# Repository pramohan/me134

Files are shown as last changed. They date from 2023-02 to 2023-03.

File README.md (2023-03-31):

# 5-DoF Robot Arm for the Operation Board Game

Teammates' Github: kgauld1, harnett1, sravaniboggaram 

## Game Design
The project is based off of the game Operation. In this game, there is a board with cutouts of various shapes, each with matching game pieces that fit into the corresponding cutouts. In the classic version of the game, the goal is to remove all of the pieces from their cutouts without the player or the pieces touching the cutout edges.

Our game is a variation on Operation in which the player controls a robotic arm to remove or insert the pieces from the game board. In leveraging a robotic arm, we are also able to autonomously insert and remove pieces from the board. As such, the goal is to make a fully functional game in which the robot can autonomously control the board state, as well as respond to manual commands from a user operating a control box.

## Hardware Design
To learn more about the robot's hardware, go to [the hardware page](hardware.md).

## Software Design
To learn more about the robot's software, go to [the software page](software.md).

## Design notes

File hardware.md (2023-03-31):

[Go back](https://github.com/pramohan/me134)

## Hardware Design
We opted to construct an arm with 5 degrees of freedom and an electromagnetic end effector. There is a pan DOF at both the base and end effector, with 3 tilt DOFs chained together between them. As it has the highest torque requirement, we chose an X8-16 Nm motor for the base tilt joint. All other motors were X5-9 or X5-4 motors, as they required lower torque ranges. For the end effector, we chose a 5V electromagnet with a 2.5kg mass rating. The electromagnet was directly mounted to the bottom of the last panning motor to give us direct rotational freedom in its positioning. The use of an electromagnet limited us to making the game pieces out of thin 30 gauge steel sheet metal, which can be easily picked up and dropped by the electromagnet. The image below displays the constructed robot arm.


We designed the game board by laser cutting a 2ft x 2ft acrylic sheet. The board, pieces, and holes were distinct colors from both each other and the table. This enabled us to identify and classify gameboard components by color. The board is shown below.


For detecting contact between the game board and the piece during gameplay we chose to implement capacitive touch sensing which required copper tape, an ESP32 Wroom, and roughly 0.75m of 30 AWG wire. The ESP32 was chosen since we already had a board and it natively has capacitive touch pins to make measurements easy to read with one command. While this has not been integrated in the current system–given our priorities in getting more complex systems such as camera detection working–its isolated tests were successful.

For the manual control, there are two modes of operation. The first mode leverages 5 potentiometers in directly controlling the angles of each of the arm joints. The second mode uses a joystick to control the cartesian velocity of the tip of the robot. There is a toggle switch to switch between the two modes, as well as a toggle switch to change the z direction of the joystick (which is controlled by pressing down on the joystick). There are also 3 LEDs to indicate the status of the internal microcontroller as well as which mode is active at the time of operation. The control box is enclosed within a laser-cut acrylic box measuring 10x15x30 cm.


The final hardware diagram is displayed below:


[Go back](https://github.com/pramohan/me134)

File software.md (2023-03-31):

[Go back](https://github.com/pramohan/me134)
# Software Setup

## Detectors
A Logitech web camera mounted above the table gave an aerial view of the game board.
 
The camera has multiple uses, one for reporting points of interest in the table frame, and another for detecting color contour boundaries. When the program is run, the 
camera waits and watches for 4 specific ARUCO tags before continuing. It then correlates the pixel position of the tags with their known table frame coordinates in order 
to compute a matrix that can compute the transform from camera coordinates to table coordinates. This process is run each time at startup, so it is robust to changes in 
table or camera location - as long as the ARUCOs are located at the same table coordinates, the position of the tags in the camera does not matter. Measuring the 
location of the tags with sub-centimeter accuracy in the table frame allowed the camera to return table frame coordinates of points of interest with sub-centimeter 
accuracy as well. We programmed our executable to wait until this camera setup is complete, so the robot will not move until all four ARUCOs are visible. An image of ARUCO detection is displayed below.



The other use of the camera is as a color contour detector. The pieces for our game were dark pink, and the board was placed on top of green felt, so that the holes could be detected by looking for green color. Finally, the board itself was blue. We tuned the HSV intervals of the detector until it could detect the boundaries of the pieces and holes with very little noise. This contour also allowed us to obtain its centroid, and thus the center of the piece. 

We attempted to obtain orientation of the pieces by using PCA; however, this only successfully worked for the bone-shaped piece. This method returned noisy and jittery angles for the other pieces. To get around this issue, we developed another method of obtaining orientation, which involved getting the line segment from the centroid to the point on the contour farthest from the centroid, and finding the angle of the segment. We were able to differentiate the bone from the other pieces using the ratio of the sides of the minimum area bounding rectangle, which was further from 1 because of its elongated shape. Thus, we could use PCA on the bone-shaped piece, and our custom orientation method on the other pieces. 



Additionally, we could use the cv2.matchShapes function to measure similarity between piece and hole contours. This allowed us to match pieces to their respective holes during autonomous board setup. In the picture below, we can see dissimilarity coefficients between the red star and each of the holes. This means that the smaller the number is, the better match it is to the star. As expected, the star shaped hole contains the smallest dissimilarity coefficient. 



The blue color of the board was only used during the automated removal of pieces from the game board.  We fit a rectangle to the blue contour, and only remove pieces if their centroid falls within the bounds of the rectangle. 

## Micro-ROS
Our controller was implemented using micro-ROS. The micro-ROS framework allows us to create a node on an Arduino Nano RP2040 Connect which transmits state information over serial communication. To establish this connection, we built a micro-ROS agent on the NUC, which read in serial data from the node on the RP2040. This worked fine, but after some time began causing a data stream conflict with the Ethernet connection to the Hebi motors. Due to this conflict, we were forced to find an alternative way to connect the controller to the main ROS node on the NUC. To this effect, we flashed a Raspberry Pi 4 with Ubuntu Jammy 22.04 running ROS 2 Humble and created a WiFi link to the NUC over the robotnet network. By establishing an SSH connection between the NUC and Raspberry Pi, we were able to wirelessly transmit publishers and subscribers between the two computers.

All development on the Micro-ROS node was done in C++, using the rclcpp library to communicate with ROS and the Arduino library to read GPIO data. Code was flashed to the microcontroller using PlatformIO in VSCode, which allowed for flashing the microcontroller with the micro-ROS firmware.
We ran into two major issues with the RP2040 Connect. The first of these issues was due to the lack of available analog pins. The RP2040 Connect has 8 analog pins onboard, but only 4 of these pins are accessible for use, as the micro-ROS firmware locks the last 4 analog pins for wireless transport modes, which we did not use. Since we needed to use 5 potentiometers for joint control and 2 for the joystick, we needed to expand the number of analog ports available on the RP2040. As such, we added an MCP3008 IC to the system, which adds 8 analog inputs through an Analog-Digital Converter (ADC) communicating to the RP4040 through the Serial Peripheral Interface (SPI). 

Our second major issue was due to the limitations of micro-ROS. The micro-ROS firmware defines the controller as “very low mem”, allowing for no more than 2 publishers and 1 subscriber. Ideally, we would have had multiple binary publishers for each button, so this forced us to create 2 Int64 subscribers which contained all of the data for the various components in its digits. The first of these subscribers was for the potentiometer values, with 15 digits, with each potentiometer value ranging from 0 to 999. The second publisher published the joystick as the first 7 digits with 3 for each direction and 1 for the up/down button, followed by 3 digits for the button/toggle switch states and one digit for the state of the capacitive touch sensor.

## Manual Control
Our primary means of motion integration was done through the implementation of splines taking the robot through either task or joint space. We begin by integrating the manual control. For manual control, we subscribe to the topics from the micro-ROS node over the network. For each of these control modes, there is a unique starting position. For the joint control, we want to set the joints to match the initial potentiometer position, while for joystick control we want to set the joints to a safe position specific to the joystick operation. After setting these segments, we update the position directly with filtered input values. 

For potentiometer control, we implement a first-order filter on the potentiometer rotation values. This creates a smoothed update sequence, so we are able to directly write the filtered potentiometer positions to the HEBIs after the startup splines are complete.

For joystick control, we have constant velocity control in the direction of the joystick. As the velocity is sufficiently slow, we are able to numerically integrate, adding a set distance at every time step of the runtime. The nominal velocity control adds 1 mm per time step, giving a velocity of 10cm/s. By maxing out the control range in either direction, the velocity can increase up to a maximum velocity of 20 cm/s in either direction. As this motion is fairly slow, the robot is able to move smoothly while controlled. To implement the actual control, we have a saved desired joystick position variable which updates with the velocity command. At each time step, the ikin of this desired position is computed, and the resultant joint states are sent to the motor controller.

Now, we must switch between the two manual control modes based on the state of the select toggle switch on the controller box. At the beginning of the update loop for each mode, there is a check for a mode mismatch. If the software operation mode does not match the controller toggle switch, the mode is switched by executing the initial spline case for the selected mode.

## Autonomous Control
We also had 2 separate modes of autonomous control. For these modes, we subscribe to the detector topics to find the position of contours and their matches. Both of these methods start with the same spline, sending the robot off of the board to make sure the entire board can be seen by the camera. 

First, we consider autonomous removal from the board. For this, we only care about the subscriber giving the list of pieces currently on the board. We send the robot to the safe position at the start, then check the board. If there are any pieces on the board, it picks one and updates the list of splines to take it off the board. The removal motion goes to a point directly above the dropoff location, then moves straight down to drop the piece. This ensures the robot does not move into the board while moving to the dropoff location.
 
Autonomous insertion has a similar movement path to the autonomous removal, but instead of 3D splines in xyz cartesian space, we must compute splines in 5D xyz tilt pan space, as we are controlling the final pan angle of the tip to ensure the piece has the right orientation when being dropped in. 

For overlapping chunks, we have a list of positions which do not match holes on the board. If there are no more pieces which match holes on the board, we go to this list and move the first centroid to one of 4 safe positions. After moving this centroid, it rechecks the board and continues. This allows for overlapping pieces to be moved then matched to hole shape to place onto the board.

Combining manual and autonomous motion, we have a flag in the code which determines the mode and any transitions. Currently, the flag is set such that the robot completes one of the two autonomous motions then switches to user input, but the modes are built with modularity in mind, so these transitions can be easily switched.

The complete diagram of the software is shown below:


[Go back](https://github.com/pramohan/me134)

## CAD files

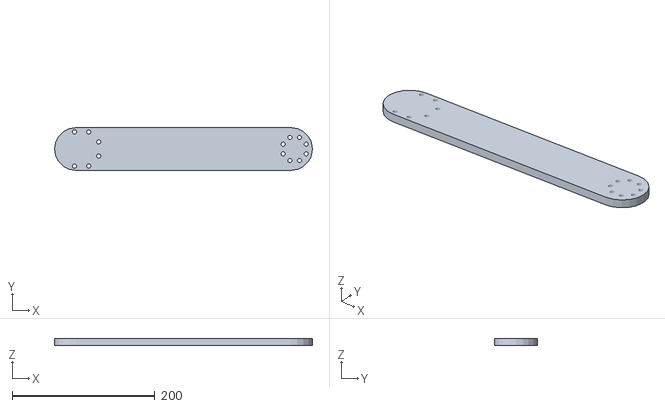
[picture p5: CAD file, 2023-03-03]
install/basic134/share/basic134/meshes/link.STL
362.0 x 60.0 x 10.0

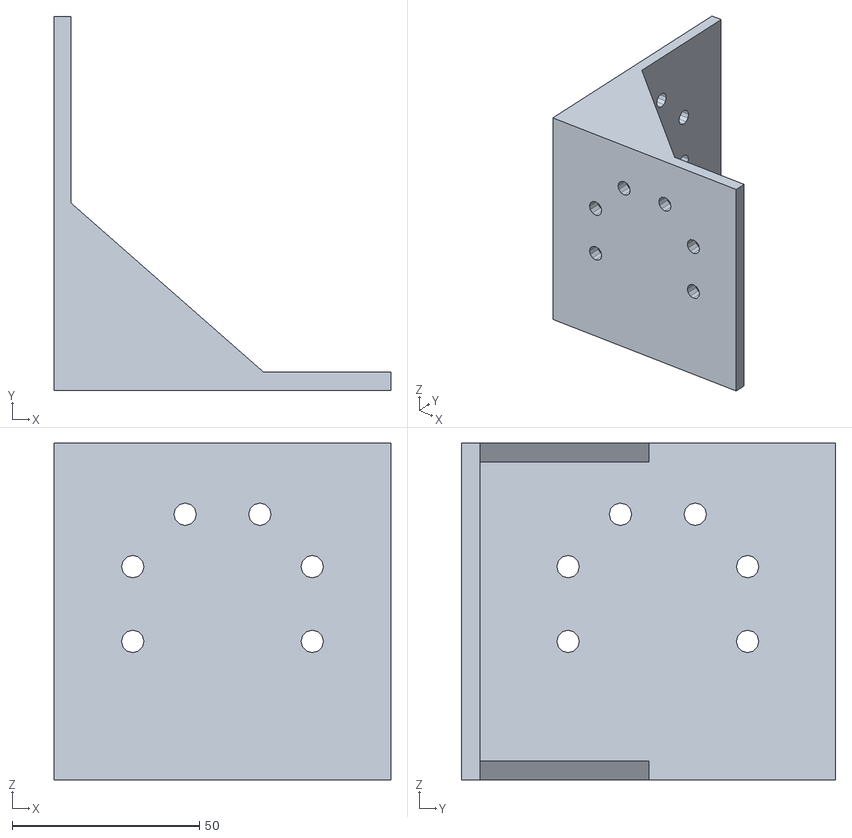
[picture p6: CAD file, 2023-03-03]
install/operation/share/operation/meshes/lbracket2.STL
90.0 x 100.0 x 90.0

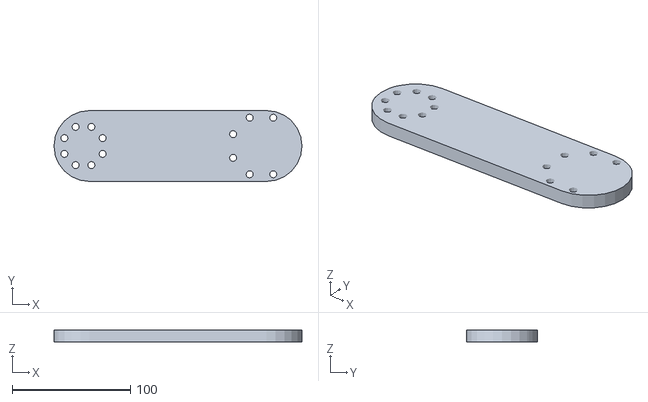
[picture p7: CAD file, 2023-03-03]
install/basic134/share/basic134/meshes/link_short.STL
210.0 x 60.0 x 10.0

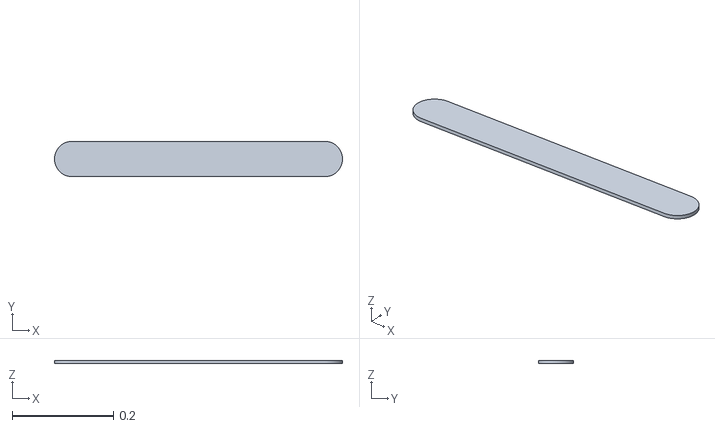
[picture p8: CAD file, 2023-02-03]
install/basic134/share/basic134/meshes/basiclink.stl
0.57 x 0.07 x 0.00635

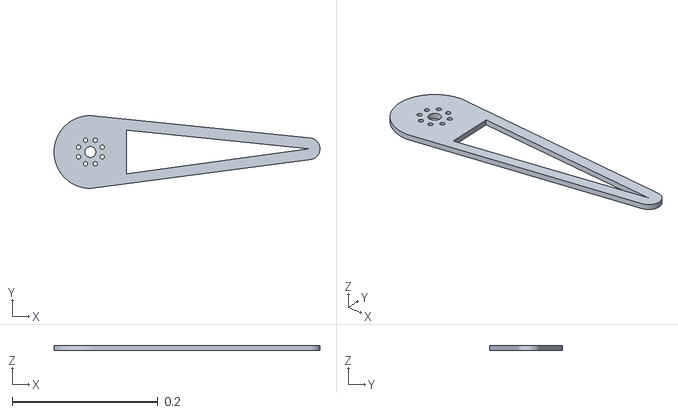
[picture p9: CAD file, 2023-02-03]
install/basic134/share/basic134/meshes/lowerarm.stl
0.365 x 0.1 x 0.00635

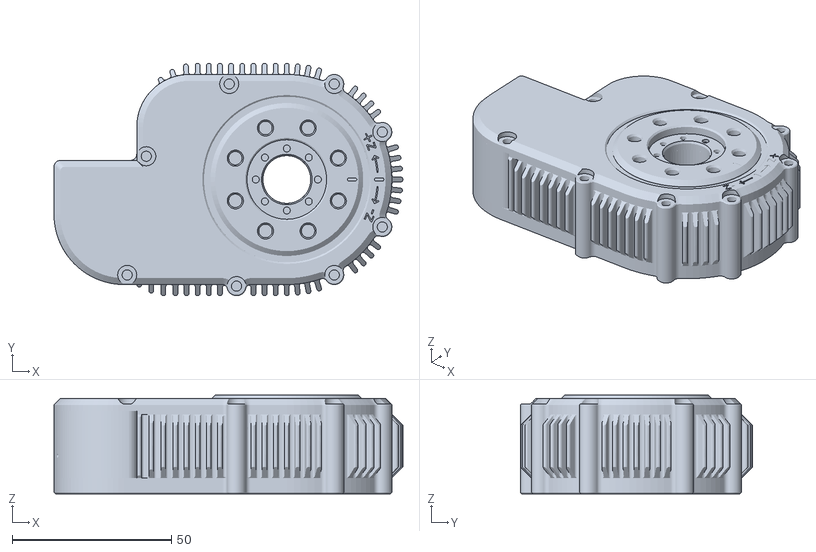
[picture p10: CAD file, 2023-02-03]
install/operation/share/operation/meshes/X5.stl
109.6 x 73.0 x 31.1

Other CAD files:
build/basic134/meshes/link.STL
build/operation/meshes/link_short.STL
build/basic134/meshes/link_short.STL
build/operation/meshes/link.STL
build/basic134/meshes/basiclink.stl
build/operation/meshes/arm_base.stl
build/basic134/meshes/arm_base.stl
build/operation/meshes/lbracket.STL
build/basic134/meshes/lowerarm.stl
build/operation/meshes/basiclink.stl
build/basic134/meshes/X5.stl
build/basic134/meshes/X8.stl
build/basic134/meshes/lbracket.STL
build/operation/meshes/X5.stl
build/operation/meshes/X8.stl
build/operation/meshes/lbracket2.STL
build/operation/meshes/lowerarm.stl
install/basic134/share/basic134/meshes/X8.stl
install/basic134/share/basic134/meshes/arm_base.stl
install/basic134/share/basic134/meshes/lbracket.STL
install/operation/share/operation/meshes/X8.stl
install/operation/share/operation/meshes/arm_base.stl
install/operation/share/operation/meshes/lbracket.STL

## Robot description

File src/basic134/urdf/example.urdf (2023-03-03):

<?xml version="1.0"?>

<robot name="example">
  
  <!-- *************************************************** -->
  <!-- ***************** Kinematic Chain ***************** -->
  <!-- *************************************************** -->
  <!-- Note the 'origin' tag in the joints defines the
       shift and reorientation before the continuous joint
       rotates around the 'axis'. -->


  <!-- Locate the base plate at the world origin. -->
  <joint name="place" type="fixed">
    <parent link="world"/>
    <child link="baseplate"/>
    <origin xyz="0 0 0" rpy="0 0 0"/>
  </joint>

  <!-- Shift across the base plate to the base motor. -->
  <joint name="baseplate" type="fixed">
    <parent link="baseplate"/>
    <child link="basemotor"/>
    <origin xyz="0.08 0 0.012" rpy="0 0 0"/>
  </joint>

  <!-- Base motor.  Thickness: X5 = 31.1mm, X8 = 45.1mm -->
  <joint name="base" type="continuous">
    <parent link="basemotor"/>
    <child link="lbracket"/>
    <origin xyz="0 0 0.0311" rpy="0 0 0"/>
    <axis xyz="0 0 1"/>
  </joint>

  <!-- Shift across the L bracket -->
  <joint name="lbracket" type="fixed">
    <parent link="lbracket"/>
    <child link="shouldermotor"/>
    <origin xyz="0 -0.035 0.075" rpy="1.5708 0 3.1415"/>
  </joint>

  <!-- Shoulder motor.  Thickness: X5 = 31.1mm, X8 = 45.1mm -->
  <joint name="shoulder" type="continuous">
    <parent link="shouldermotor"/>
    <child link="upperarm"/>
    <origin xyz="0 0 0.0451" rpy="0 0 0"/>
    <axis xyz="0 0 1"/>
  </joint>

  <!-- Shift across the upper arm (1/4in thickness) -->
  <joint name="upperarm" type="fixed">
    <parent link="upperarm"/>
    <child link="elbowmotor"/>
    <origin xyz="0 0.3 0" rpy="0 3.1415 -1.5708"/>
  </joint>

  <!-- Elbow motor.  Thickness: X5 = 31.1mm, X8 = 45.1mm -->
  <joint name="elbow" type="continuous">
    <parent link="elbowmotor"/>
    <child link="lowerarm"/>
    <origin xyz="0 0 .0311" rpy="0 0 0"/>
    <axis xyz="0 0 1"/>
  </joint>

  <!-- Shift across the upper arm (1/4in thickness) -->
  <joint name="lowerarm" type="fixed">
    <parent link="lowerarm"/>
    <child link="wristmotor"/>
    <origin xyz="0 0.30095 0" rpy="0 3.1415 1.5708"/>
  </joint>

  <!-- Wrist motor.  Thickness: X5 = 31.1mm, X8 = 45.1mm -->
  <joint name="wrist" type="continuous">
    <parent link="wristmotor"/>
    <child link="hand"/>
    <origin xyz="0 0 .0311" rpy="0 0 0"/>
    <axis xyz="0 0 1"/>
  </joint>

  <!-- Shift across the hand (1/4in thickness) -->
  <joint name="hand" type="fixed">
    <parent link="hand"/>
    <child link="lbracket2"/>
    <origin xyz="0 0.15266 0" rpy="0 0 0"/>
  </joint>

  <!-- Shift across the second L bracket -->
  <joint name="lbracket2" type="fixed">
    <parent link="lbracket2"/>
    <child link="fingermotor"/>
    <origin xyz=".045 0 -0.0525" rpy="-1.5708 0 -1.5708"/>
  </joint>

  <!-- Finger motor.  Thickness: X5 = 31.1mm, X8 = 45.1mm -->
  <joint name="finger" type="continuous">
    <parent link="fingermotor"/>
    <child link="tip"/>
    <origin xyz="0 0 .0311" rpy="0 0 0"/>
    <axis xyz="0 0 1"/>
  </joint>
  
  <!-- *************************************************** -->
  <!-- *************** Visual Link Elements ************** -->
  <!-- *************************************************** -->
  <!-- Note collada .dae files have better color/texture   -->
  <!-- suppport that STL files.                            -->

  <!-- Colors -->
  <material name="wood">  <color rgba="0.82 0.62 0.04 1"/>  </material>
  <material name="hebi">  <color rgba="0.82 0.06 0.06 1"/>  </material>

  <!-- World can't take a visual element (at least in Gazebo). -->
  <link name="world"/>

  <link name="baseplate">
    <visual>
      <origin xyz = "0.07 0 0" rpy = "0 0 0"/>
      <geometry>
        <cylinder length="0.012" radius="0.08"/>
      </geometry>
      <material name="wood"/>
    </visual>
  </link>

  <link name="basemotor">
    <visual>
      <geometry>
        <mesh filename="package://basic134/meshes/X5.stl" scale="0.001 0.001 0.001"/>
      </geometry>
      <material name="hebi"/>
    </visual>
  </link>

  <link name="lbracket">
    <visual>
      <origin xyz = "0.038 0.03 0" rpy = "0 0 3.1415"/>
      <geometry>
        <mesh filename="package://basic134/meshes/lbracket.STL" scale="0.001 0.001 0.001"/>
      </geometry>
      <material name="wood"/>
    </visual>
  </link>

  <link name="shouldermotor">
    <visual>
      <geometry>
        <mesh filename="package://basic134/meshes/X8.stl" scale="0.001 0.001 0.001"/>
      </geometry>
      <material name="hebi"/>
    </visual>
  </link>

  <link name="upperarm">
    <visual>
      <origin xyz = "0 0.15 0.0065" rpy = "0 1.5708 1.5708"/>
      <geometry>
        <mesh filename="package://basic134/meshes/arm_base.stl" scale="0.001 0.001 0.001"/>
      </geometry>
      <material name="wood"/>
    </visual>
  </link>

  <link name="elbowmotor">
    <visual>
      <geometry>
        <mesh filename="package://basic134/meshes/X5.stl" scale="0.001 0.001 0.001"/>
      </geometry>
      <material name="hebi"/>
    </visual>
  </link>

  <link name="lowerarm">
    <visual>
      <origin xyz = "0.03 0.337 0.01" rpy = "3.1415 0 -1.5708"/>
      <geometry>
        <mesh filename="package://basic134/meshes/link.STL" scale="0.001 0.001 0.001"/>
      </geometry>
      <material name="wood"/>
    </visual>
  </link>

  <link name="wristmotor">
    <visual>
      <geometry>
        <mesh filename="package://basic134/meshes/X5.stl" scale="0.001 0.001 0.001"/>
      </geometry>
      <material name="hebi"/>
    </visual>
  </link>

  <link name="hand">
    <visual>
      <origin xyz = "0.03 -0.0247 0" rpy = "0 0 1.5708"/>
      <geometry>
        <mesh filename="package://basic134/meshes/link_short.STL" scale="0.001 0.001 0.001"/>
      </geometry>
      <material name="wood"/>
    </visual>
  </link>

  <link name="lbracket2">
    <visual>
      <origin xyz = "0.045 0.0503 0" rpy = "-1.5708 0 3.1415"/>
      <geometry>
        <mesh filename="package://operation/meshes/lbracket2.STL" scale="0.001 0.001 0.001"/>
      </geometry>
      <material name="wood"/>
    </visual>
  </link>

  <link name="fingermotor">
    <visual>
      <geometry>
        <mesh filename="package://basic134/meshes/X5.stl" scale="0.001 0.001 0.001"/>
      </geometry>
      <material name="hebi"/>
    </visual>
  </link>
  
  <link name="tip"/>

</robot>

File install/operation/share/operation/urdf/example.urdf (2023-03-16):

<?xml version="1.0"?>

<robot name="KillerRover2000">
  
  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
  <joint name="place" type="fixed">
    <parent link="world"/>
    <child link="baseplate"/>
    <origin xyz="0 0 0" rpy="0 0 0"/>
  </joint>

  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
  <joint name="baseplate" type="fixed">
    <parent link="baseplate"/>
    <child link="motor0"/>
    <origin xyz="0 0 0" rpy="0 0 0"/>
  </joint>

  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
  <joint name="theta0" type="continuous">
    <parent link="motor0"/>
    <child link="basecylinder"/>
    <origin xyz="0 0 0" rpy="0 0 0"/>
    <axis xyz="0 0 1"/>
  </joint>

  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
  <joint name="basecylinder" type="fixed">
    <parent link="basecylinder"/>
    <child link="motor1link"/>
    <origin xyz="0 0 0.0127" rpy="0 0 0"/>
  </joint>

  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
  <joint name="motor1link" type="fixed">
    <parent link="motor1link"/>
    <child link="motor1"/>
    <origin xyz="0.0225 0.017 0.0902" rpy="0 0 0"/>
  </joint>

  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
  <joint name="theta1" type="continuous">
    <parent link="motor1"/>
    <child link="motor2link"/>
    <origin xyz="0 0 0" rpy="0 0 0"/>
    <axis xyz="1 0 0"/>
  </joint>

  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
  <joint name="motor2link" type="fixed">
    <parent link="motor2link"/>
    <child link="motor2"/>
    <origin xyz="0.0574 0.396 0.0" rpy="0 0 0"/>
  </joint>

  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
  <joint name="theta2" type="continuous">
    <parent link="motor2"/>
    <child link="motor3link"/>
    <origin xyz="0 0 0" rpy="0 0 0"/>
    <axis xyz="1 0 0"/>
  </joint>

  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
  <joint name="motor3link" type="fixed">
    <parent link="motor3link"/>
    <child link="motor3"/>
    <origin xyz="-0.0574 0.396 0.0" rpy="0 0 0"/>
  </joint>

  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
  <joint name="theta3" type="continuous">
    <parent link="motor3"/>
    <child link="motor4link"/>
    <origin xyz="0 0 0" rpy="0 0 0"/>
    <axis xyz="1 0 0"/>
  </joint>

  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
  <joint name="motor4link" type="fixed">
    <parent link="motor4link"/>
    <child link="motor4"/>
    <origin xyz="0 0.1535 0.0574" rpy="0 0 0"/>
  </joint>

  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
  <joint name="theta4" type="continuous">
    <parent link="motor4"/>
    <child link="tiplink"/>
    <origin xyz="0 0 0" rpy="0 0 0"/>
    <axis xyz="0 0 1"/>
  </joint>

  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
  <joint name="tiplink" type="fixed">
    <parent link="tiplink"/>
    <child link="tip"/>
    <origin xyz="0 0.1275 0" rpy="0 0 0"/>
  </joint>
  
  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
  <link name="world"/>

  <link name="baseplate">
    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
  </link>

  <link name="motor0">
    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
  </link>

  <link name="basecylinder">
    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
  </link>

  <link name="motor1link">
    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
  </link>

  <link name="motor1">
    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
  </link>

  <link name="motor2link">
    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
  </link>

  <link name="motor2">
    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
  </link>

  <link name="motor3link">
    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
  </link>

  <link name="motor3">
    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
  </link>

  <link name="motor4link">
    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
  </link>

  <link name="motor4">
    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
  </link>
  
  <link name="tiplink">
    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
  </link>

  <link name="tip"/>

</robot>

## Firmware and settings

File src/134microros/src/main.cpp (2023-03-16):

#include <micro_ros_arduino.h>

#include <stdio.h>
#include <rcl/rcl.h>
#include <rcl/error_handling.h>
#include <rclc/rclc.h>
#include <rclc/executor.h>

#include <std_msgs/msg/int64.h>
#include <std_msgs/msg/int32.h>
#include <std_msgs/msg/bool.h>
#include <std_msgs/msg/int32_multi_array.h>
#include <Adafruit_MCP3008.h>

Adafruit_MCP3008 adc;

rcl_publisher_t pot_pub;
std_msgs__msg__Int64 pot_msg;

rcl_publisher_t joy_pub;
std_msgs__msg__Int64 joy_msg;

rcl_subscription_t subscriber;
std_msgs__msg__Int32 msg;

rclc_executor_t executor_pub;
rclc_executor_t executor_sub;

rclc_support_t support;
rcl_allocator_t allocator;
rcl_node_t node;
rcl_timer_t timer;


int count_ones;

#define RCCHECK(fn) { rcl_ret_t temp_rc = fn; if((temp_rc != RCL_RET_OK)){error_loop();}}
#define RCSOFTCHECK(fn) { rcl_ret_t temp_rc = fn; if((temp_rc != RCL_RET_OK)){}}


#define LED_PIN 2

#define T_sw 8
#define EM_sw 7
#define C_touch 6
#define J_dir 4

#define EM_out 5

#define SCK 13
#define MISO 12
#define MOSI 11
#define CS 10

void error_loop(){
  while(1){
    digitalWrite(LED_PIN, !digitalRead(LED_PIN));
    delay(100);
  }
}

int64_t readPots() {
  int64_t joints = 0;
  for(int i=0; i<5;i++) {
    joints *= 1000;
    int v = adc.readADC(i)*1000/1024;
    joints += (v > 999) ? 999 : v;
  }
  return joints;
}

int64_t readJoystick() {
  int64_t joints = 0;
  for(int i=5; i<7;i++) {
    joints *= 1000;
    int v = adc.readADC(i)*1000/1024;
    joints += (v > 999) ? 999 : v;
  }
  int button = digitalRead(9);
  if(button == 1) count_ones+=1;
  else count_ones=0;

  if(count_ones >= 20){
    count_ones = 20;
    button = 1;
  } else button=0;
  joints = joints*100000 + 
           button*10000 + 
           digitalRead(T_sw)*1000 + 
           digitalRead(EM_sw)*100 + 
           digitalRead(C_touch)*10 +
           digitalRead(J_dir);

  return joints;
}

void timer_callback(rcl_timer_t * timer, int64_t last_call_time) {  
  RCLC_UNUSED(last_call_time);
  if (timer != NULL) {
    RCSOFTCHECK(rcl_publish(&pot_pub, &pot_msg, NULL));
    pot_msg.data = readPots();
    RCSOFTCHECK(rcl_publish(&joy_pub, &joy_msg, NULL));
    joy_msg.data = readJoystick();
  }
}

void subscription_callback(const void * msgin) {
	const std_msgs__msg__Int32 * msg = (const std_msgs__msg__Int32 *)msgin;
  if(msg->data > 0) digitalWrite(EM_out, HIGH);
  else digitalWrite(EM_out, LOW);
}

// void subscription_callback(const void * msgin)
// {
// 	const std_msgs__msg__Int32 * msg = (const std_msgs__msg__Int32 *)msgin;
// 	//printf("Received: %d\n", msg->data);
// }

void setup() {
  analogReadResolution(10);
  set_microros_transports();
  count_ones = 0;

  pinMode(LED_PIN, OUTPUT);

  pinMode(T_sw, INPUT);
  pinMode(EM_sw, INPUT);
  pinMode(C_touch, INPUT);
  
  pinMode(EM_out, OUTPUT);

  digitalWrite(LED_PIN, HIGH);  
  
  adc.begin();
  delay(2000);

  allocator = rcl_get_default_allocator();

  //create init_options
  RCCHECK(rclc_support_init(&support, 0, NULL, &allocator));

  // create node
  RCCHECK(rclc_node_init_default(&node, "rp2040_pots", "", &support));

  // create publisher  unsigned int num_handles_pub = 2;
  RCCHECK(rclc_publisher_init_default(
    &pot_pub, &node,
    ROSIDL_GET_MSG_TYPE_SUPPORT(std_msgs, msg, Int64),
    "pot_val"));
  
  RCCHECK(rclc_publisher_init_default(
    &joy_pub, &node,
    ROSIDL_GET_MSG_TYPE_SUPPORT(std_msgs, msg, Int64),
    "sensors"));

  RCCHECK(rclc_subscription_init_default(
		&subscriber,
		&node,
		ROSIDL_GET_MSG_TYPE_SUPPORT(std_msgs, msg, Int32),
		"EM_enable"));

  // create timer,
  const unsigned int timer_timeout = 10;
  RCCHECK(rclc_timer_init_default(
    &timer, &support,
    RCL_MS_TO_NS(timer_timeout),
    timer_callback));

  // create executor
  RCCHECK(rclc_executor_init(&executor_pub, &support.context, 2, &allocator));
  RCCHECK(rclc_executor_add_timer(&executor_pub, &timer));

  RCCHECK(rclc_executor_init(&executor_sub, &support.context, 1, &allocator));
  RCCHECK(rclc_executor_add_subscription(&executor_sub, &subscriber, &msg, &subscription_callback, ON_NEW_DATA));
  

  pot_msg.data = 0;
  joy_msg.data = 0;
}

void loop() {
  delay(1);
  RCSOFTCHECK(rclc_executor_spin_some(&executor_pub, RCL_MS_TO_NS(1)));
  RCSOFTCHECK(rclc_executor_spin_some(&executor_sub, RCL_MS_TO_NS(1)));
}

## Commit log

2023-02-24 final basic134
    [X5.stl, X8.stl, arm_base.stl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]
2023-03-03 5DOF URDF, ikin with level tip
    [X5.stl, X8.stl, arm_base.stl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]
2023-03-16 final commit
    [X5.stl, X8.stl, arm_base.stl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]
2023-03-18 insertion complete
